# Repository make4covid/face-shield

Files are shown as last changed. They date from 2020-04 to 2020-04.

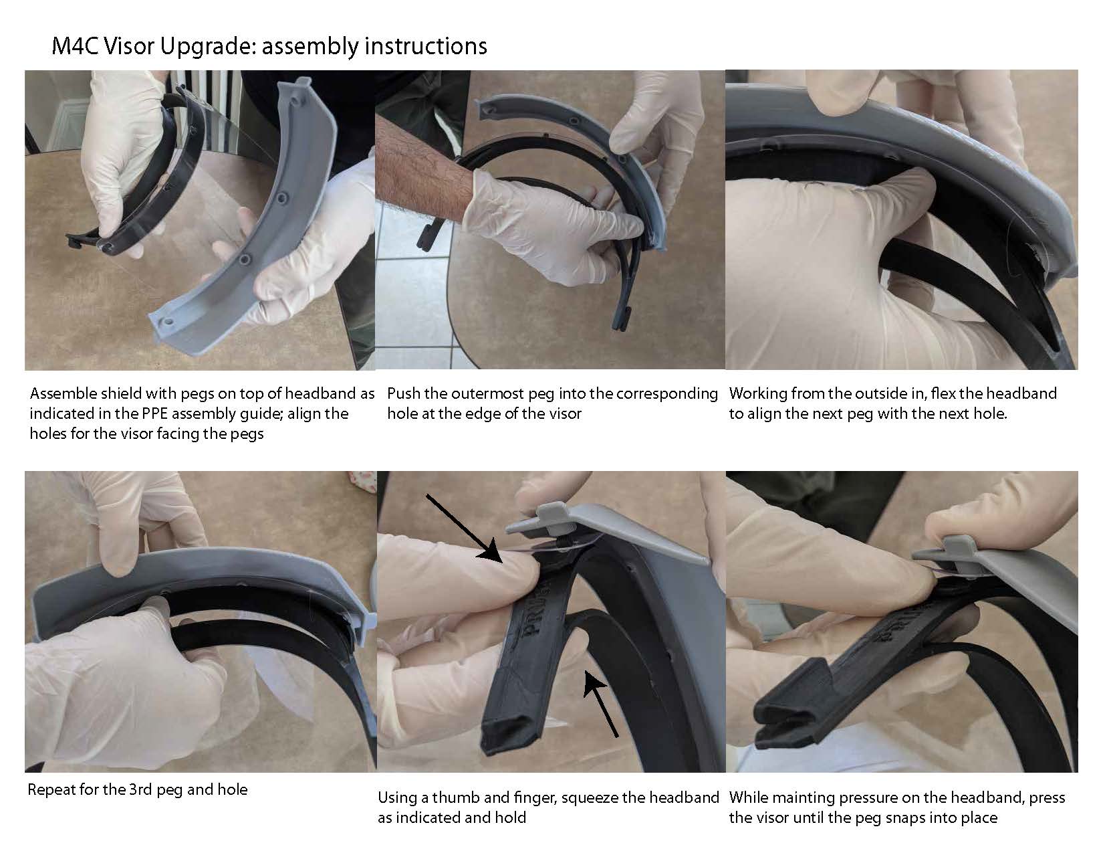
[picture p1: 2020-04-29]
M4C visor assembly instructions v1.jpg

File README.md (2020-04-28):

# Make4Covid Face Shield
### Based on the [Prusa design](https://www.prusaprinters.org/prints/25857-prusa-protective-face-shield-rc3)

This repo contains the face shield currently in production by the Make4Covid
organization. The Make4Covid design is based on [this design from Prusa](https://www.prusaprinters.org/prints/25857-prusa-protective-face-shield-rc3).

Prusa's files were released under the CC BY-SA-NC license.

**For everyone's safety, please read and follow our Standard Operating Procedures (SOPs) while making PPE for use during the COVID-19 pandemic.**

### Next Steps
1. Find, read, re-read, memorize, and bookmark [the M4C SOPs](https://github.com/make4covid/sop).
2. Download the [latest release](https://github.com/make4covid/face-shield/releases) of the design files.
3. Use the SOPs to safely make the gear!
1. If you're interested, learn [how to contribute](https://github.com/make4covid/face-shield/blob/master/CONTRIBUTING.md).

If you're in Colorado, please join our community by visiting make4covid.co and clicking 'Join.' This will allow you to connect with other Colorado makers and to leverage or growing network and supply chain to get what you make to where it's needed most!

# Derivative Design Disclaimer

These designs have been tested for comfort and safety by frontline healthcare professionals. Other people and organizations are welcome to use these designs to provide PPE to anyone who needs it.

You can fork these designs and make changes under the CC license, but in doing so, you assume liability. We encourage you to use the M4C designs unless you have the resources and facilities to adequately field-test any updated components.

# Issues?
If you find a problem with a design, compatibility between files, safety, documentation, or suggestions for improvement, please [open an issue.](https://github.com/make4covid/face-shield/issues/new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)

# Github for _hardware?_
It's not unheard of. Here are some things to keep in mind.
* Diffs don't mean much on binary files, so don't worry about them.
* Github _can_ show visual diffs on `.stl` files, so it's helpful to include them in addition to other CAD file types.
* Merging is also a challenge with binaries. Replace whole files or coordinate to avoid merge conflicts.
* Hardware repos can get huge, but you don't have to clone down everything to contribute.
* If the repo gets too big, we can set up `git lfs` (large file storage) to trim it down.

If you have other ideas on how to optimize git for open-source hardware, please [submit an issue](https://github.com/make4covid/face-shield/issues/new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) to let us know!

# Awesome Make4Covid
Check out the [Awesome M4C](https://github.com/make4covid/awesome-make4covid) repo for tons of helpful resources.

# Make4Covid
Make4Covid website is available here:

* https://www.make4covid.co/

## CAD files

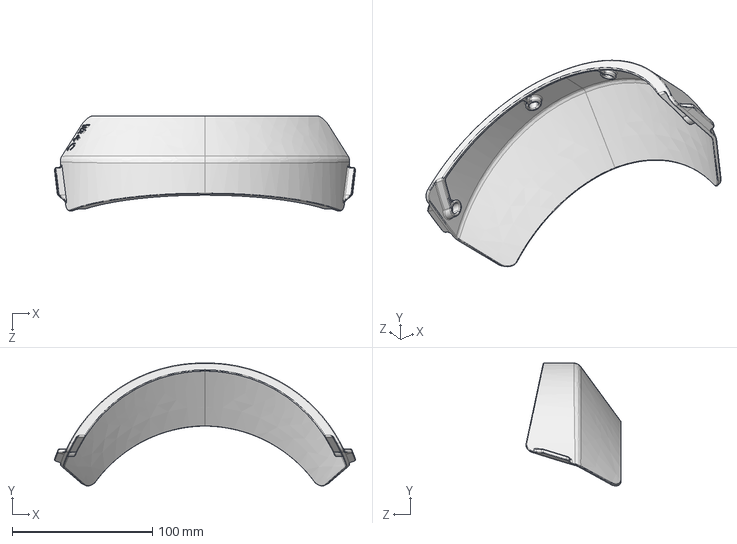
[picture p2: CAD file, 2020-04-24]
3dprint/M4C Visor Shield Rev F.1.STEP
214.6 x 87.7 x 67.8 mm

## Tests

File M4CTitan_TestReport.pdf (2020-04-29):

Face Shield Test Report M4C Titan Face Shield April 20, 2020

## 1. Summary

This report provides results from testing conducted by the Bioengineering Department on the Anschutz Medical Campus in Aurora Colorado. Test procedures were adapted from the American National Standards Institute (ANSI) standard Z87.1-2003 [1] and guidelines compiled for the Journal of Occupational and Environmental Hygiene [2]. This test does not assess mechanical impacts.

1.1. Test Articles
Test articles reported on are described in Table 1.

Table 1: Test articles.
Test Article | Part #/Lot # | Number of Samples | Material | Date
Make4Covid Titan Face Shield w/ Visor | Not Provided | 2 Shields 2 Halos 2 V1 Visors 2 V2 Visors 1 TPU Band | PETG PETG PETG PETG TPU | 4/20/2020
1.2. Results Summary
Results are summarized
in Table 2. Specifications were derived from the
ANSI standards and the
clinical guidelines [1,2]. When the shields arrived,
they were assembled
according to the
instructions for use
(Figure 1). The shields
studied were functional,

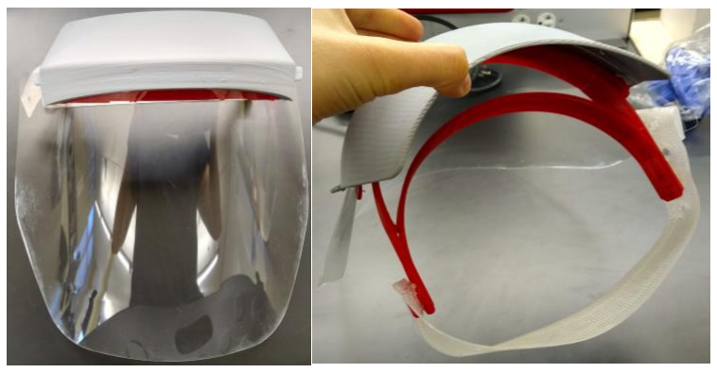
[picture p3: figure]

demonstrating no flammability, no liquid penetration during spraying, and no vision impairment or degradation after cleaning. The shields studied were not biocompatible, demonstrating irritation after 30 minutes of wear. The shields studied demonstrated no shifting during use, but both visor models popped off the shield during shield donning and doffing (Video in M4C Titan folder).

1.3. Recommendations
The tester attempted to remove the films with a razor blade (as pictured in the instructions for use) and accidentally cut off a portion of the shield edge. To improve ease of use and prevent damage, it is recommended that the film edge

Figure 1: Assembled test article.

is partially lifted for quick and damage-free film removal. To prevent the visors from popping off the halos during donning and doffing, a reduction in flexibility of the front portion of the halo is recommended. The tester experienced hair catching on the TPU band during wear tests. To improve usability, it is recommended that a non-sticky elastic securement method be used. To improve biocompatibility, it is recommended that padding be added to the forehead-contacting part of the halo.

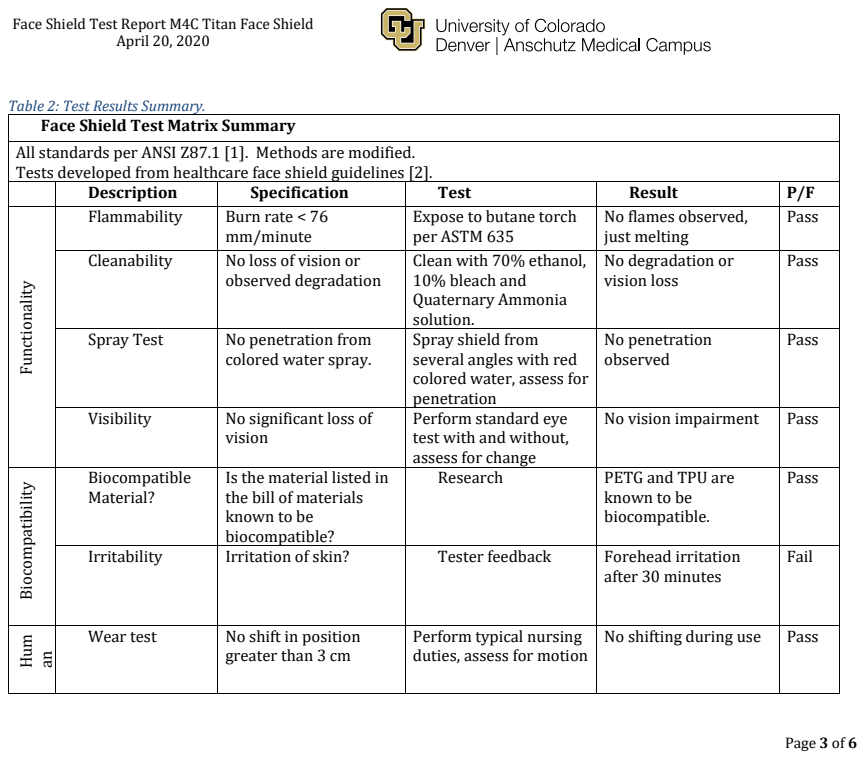
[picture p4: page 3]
April 20, 2020; Page 3 of 6; Functionality; Biocompatibility; Hum

Table 2: Test Results Summary.
Face Shield Test Matrix Summary
All standards per ANSI Z87.1 [1]. Methods are modified.
Tests developed from healthcare face shield guidelines [2].

Description | Specification | Test | Result | P/F
Flammability | Burn rate < 76 mm/minute | Expose to butane torch per ASTM 635 | No flames observed, just melting | Pass

Cleanability | No loss of vision or observed degradation | Clean with 70% ethanol, 10% bleach and Quaternary Ammonia solution. | No degradation or vision loss | Pass

Spray Test | No penetration from colored water spray. | Spray shield from several angles with red colored water, assess for penetration | No penetration observed | Pass

Visibility | No significant loss of vision | Perform standard eye test with and without, assess for change | No vision impairment | Pass

Biocompatible Material? | Is the material listed in the bill of materials known to be biocompatible? | Research | PETG and TPU are known to be biocompatible. | Pass

Irritability | Irritation of skin? | Tester feedback | Forehead irritation after 30 minutes | Fail

Wear test | No shift in position greater than 3 cm | Perform typical nursing duties, assess for motion | No shifting during use | Pass

Don/Doff time Takes no more than 30 seconds to don or doff

Measure time | 10 seconds | Pass

April 20, 2020

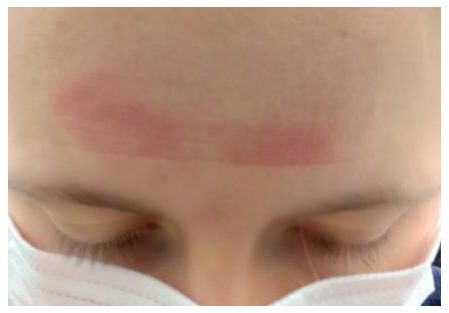
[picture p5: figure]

## 2. Results

2.1.Human Factors
When moving the head side-to-side and up-and-down repeatedly, the shield did not shift. Halo flexure caused both visor models to pop off the assembled system, which occurred during donning and doffing. In the initial wear test up to 30 minutes, forehead irritation and contact points were observed (Figure 2).

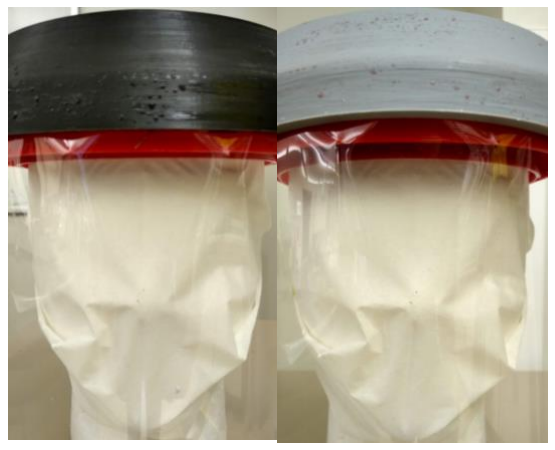
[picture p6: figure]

2.2. Spray Testing
After spraying the shield three times at eye-level from three sides, no liquid penetration was observed - no liquid was absorbed on areas protected by the face shield (Figure 3). Both visors models were tested and were functional.
2.3. Cleaning and Vision
Three test solutions, 70% ethanol, 10% bleach, and a quaternary ammonia
solution, were individually applied to
the shield before a subsequent vision
test. No damage, hazing, or reduction in vision was observed after cleaning the shield with the test solutions.
2.4. Flammability
When applying a butane flame to the shield material, no flames or burning were observed. The material melted but did not ignite. Burn rate was not recorded as no burning was observed.

## 3. Conclusion

The shield provided satisfactory visual quality and good cleanability. The visors prevented liquid penetration, but were not stable during donning and doffing. The material is not flammable and is known to be biocompatible. The tester experienced discomfort during wear.

Figure 2: User forehead after use.

Figure 3: Shield with visor model 1 (left) and visor model 2 (right) post-spray test.

## 4. References

[1] American National Standards Institute. "ANSI Z87. 1‐2003 Standard Practice for Occupational and Educational Eye and Face Protection." (2003).
[2] Roberge, Raymond J. "Face shields for infection control: A review." Journal of Occupational and Environmental Hygiene, 13.4 (2016): 235-242.

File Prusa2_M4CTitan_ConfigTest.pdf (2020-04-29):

Face Shield Test Report Prusa (v2)-Titan Face Shield Config. April 22, 2020

## 1. Summary

This report provides results from testing conducted by the Bioengineering Department on the Anschutz Medical Campus in Aurora Colorado. Test procedures were adapted from the American National Standards Institute (ANSI) standard Z87.1-2003 [1] and guidelines compiled for the Journal of Occupational and Environmental Hygiene [2]. This test does not assess mechanical impacts.

1.1. Test Articles
Test articles reported on are described in Table 1.

Table 1: Test articles.

1.2. Summary of Reconfiguration The purpose of the
following tests was
to see if
reconfiguring the
Prusa v2 shield with
visors from the Titan
system would modify
previous relevant
test results. Initially,
when using the full
Prusa v2 system with

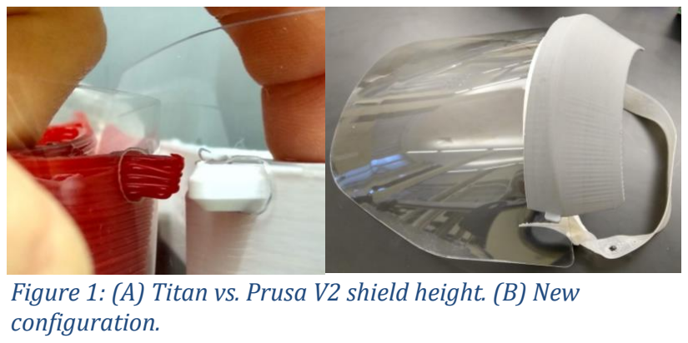
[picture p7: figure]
configuration.

the visor addition, neither visor models were able to attach to the assembly due to greater shield height (Figure 1A). Flipping the halo facilitated visor attachment successfully in the reconfigured device (Figure 1B). Both visor models were able to attach to the Prusa v2 system successfully when shield height over the halo was minimized.

Test Article | Part #/Lot # | Number of Samples | Material | Date
Prusa RC2/3 v2 | Not Provided | 2 Shields 2 Halos 2 Rubber Bands | PETG PETG | Original Tests: 4/8/2020 4/9/2020
Make4Covid Titan Face Shield w/ Visor | Not Provided | 2 Shields 2 Halos 2 V1 Visors 2 V2 Visors 1 TPU Band | PETG PETG PETG PETG TPU | Original Tests: 4/20/2020

Figure 1: (A) Titan vs. Prusa V2 shield height. (B) New

## 2. Additional Results

2.1.Usability
Halo flexure did not
cause either visor
model to pop off,
including during
donning and doffing
(Videos in
VisorConfig2 Folder).
2.2. Spray Testing
Halo flipping was
previously used to

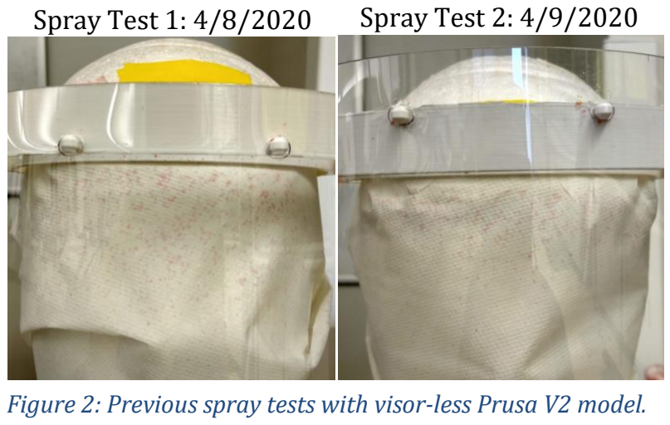
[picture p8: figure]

reduce liquid penetration in the visor-less Prusa v2
system (Figure 2). With the addition of both visor
models, no liquid
penetration was observed
(Figure 3).

## 3. Additional Conclusions

The addition of a visor has allowed the Prusa v2 system to pass spray testing. Additionally,
the Prusa v2 halo has improved
usability over the titan system

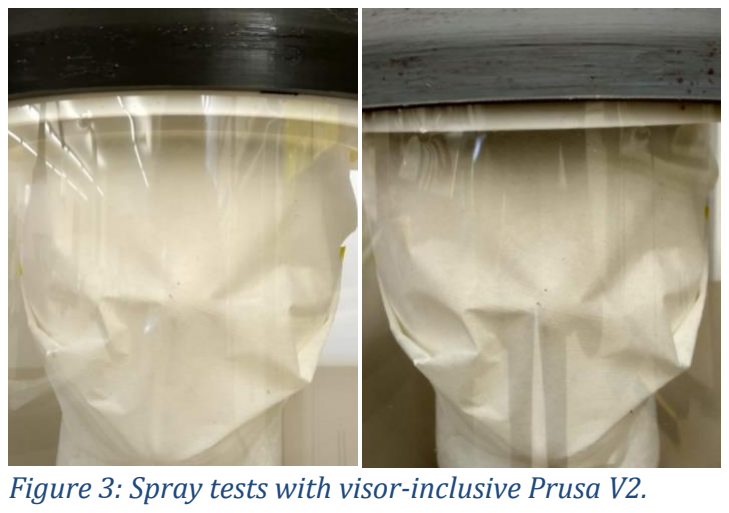
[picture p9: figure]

since flexure does not cause the visor to pop off. Given that many shield configurations are possible within these systems, visual cues on the device could ensure users can quickly assemble the system (ie. “This Side Up!”). Recommendations regarding forehead padding, the elastic strap, and shield films still remain: added padding would reduce irritability, a non-sticky elastic strap would prevent hair pulling, and peeling up the shield films slightly before shipping would improve usability.

## 4. References

[1] American National Standards Institute. "ANSI Z87. 1‐2003 Standard Practice for Occupational and Educational Eye and Face Protection." (2003).
[2] Roberge, Raymond J. "Face shields for infection control: A review." Journal of Occupational and Environmental Hygiene, 13.4 (2016): 235-24

Spray Test 1: 4/8/2020 Spray Test 2: 4/9/2020

Figure 2: Previous spray tests with visor-less Prusa V2 model.

Figure 3: Spray tests with visor-inclusive Prusa V2.

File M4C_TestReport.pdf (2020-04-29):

Face Shield Test Report Inworks Prusa Face Shield (v2) April 8, 2020

## 1. Summary

This report provides results from testing conducted by the Bioengineering Department on the Anschutz Medical Campus in Aurora Colorado. Test procedures were adapted from the American National Standards Institute (ANSI) standard Z87.1-2003 [1] and guidelines compiled for the Journal of Occupational and Environmental Hygiene [2]. This test does not assess mechanical impacts.

1.1. Test Articles
Test articles reported on are described in Table 1.

Table 1: Test articles.
Test Article | Part #/Lot # | Number of Samples | Material | Date
Prusa RC2/3 v2 | Not Provided | 2 Shields 2 Halos 2 Rubber Bands | PETG | 4/8/2020
1.2. Results Summary
Results are summarized in Table 2. Specifications were derived from the ANSI standards and the clinical guidelines [1,2]. When the test articles arrived, there appeared to be manufacturing
defects on the skin-contacting part of
the halo (Figure 1a); they otherwise
appeared as pictured on the submission form (Figure 1b). The shields studied were partially functional, demonstrating no flammability and no vision impairment or degradation after cleaning, but liquid penetration was observed during spraying. The shields tested demonstrated no shifting during use, but the rubber band made shield removal difficult due to catching of the tester’s hair. The shields studied were not biocompatible, demonstrating skin irritation after a short period of use.

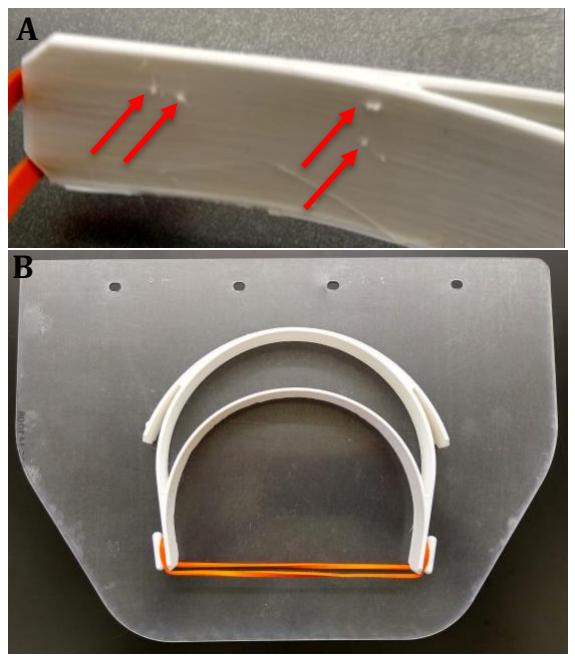
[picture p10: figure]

Figure 1: Test article upon arrival.

1.3. Recommendations
The tester spent a significant amount of the application time trying to peel the shield-covering films off. To improve ease of use and reduce user application time, it is recommended that the films be removed prior to shipment or that they be partially removed to facilitate quick removal in the clinical environment. To improve device functionality, multiple device openings should be sealed: the shield attachment points (Figure 2) and the gap between the forehead and outer halo (Figure 3). To improve biocompatibility, forehead padding would reduce redness and irritation. To prevent hair catching for user’s with longer hair, an alternative elastic backing should be considered.

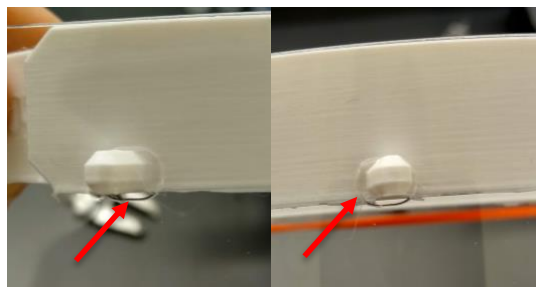
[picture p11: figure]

Figure 3: Openings at shield attachment points.

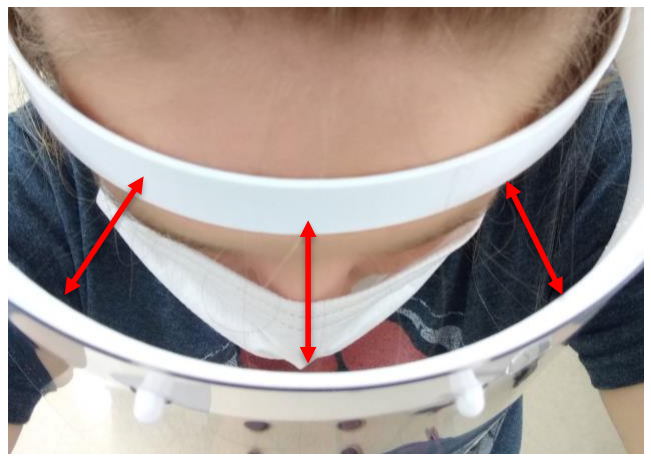
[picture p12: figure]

Figure 2: Opening between forehead and outer halo.

April 8, 2020; Page 3 of 6; Functionality; Biocompatibility

Table 2: Test Results Summary.
Face Shield Test Matrix Summary
All standards per ANSI Z87.1 [1]. Methods are modified.
Tests developed from healthcare face shield guidelines [2].

Description | Specification | Test | Result | P/F
Flammability | Burn rate < 76 mm/minute | Expose to butane torch per ASTM 635 | No flames observed, just melting | Pass

Cleanability | No loss of vision or observed degradation | Clean with 70% ethanol, 10% bleach and Quaternary Ammonia solution. | No degradation or vision loss | Pass

Spray Test | No penetration from colored water spray. | Spray shield from several angles with red colored water, assess for penetration | Penetration observed | Fail

Visibility | No significant loss of vision | Perform standard eye test with and without, assess for change | No vision impairment | Pass

Biocompatible Material? | Is the material listed in the bill of materials known to be biocompatible? | Research | PETG is known to be biocompatible | Pass

Irritability | Irritation of skin? | Tester feedback | Skin irritation and contact redness at forehead after 30 minutes, side head pain | Fail

Human Factors

Wear test | No shift in position greater than 3 cm | Perform typical nursing duties, assess for motion | No shifting during use | Pass
Don/Doff time | Takes no more than 30 seconds to don or doff | Measure time | 1.5 minutes | Fail

April 8, 2020


## 2. Results

2.1.Human Factors
When moving the head side-to-side and up-and-down repeatedly, the shield did not shift. In the initial wear test up to 30 minutes, there was skin irritation and noticeable contact points from the shield (Figure 4). The tester experienced difficulties with donning and doffing with long hair catching on the rubber band and experienced pain at the halo end points (Figure 5).


2.2. Spray Testing
After spraying the shield three times at eye-level from three sides, liquid penetration was observed on the forehead area of the test mannequin (Figure 6). It appeared that droplets made it over the gap between the forehead and halo (Figure 3).


2.3. Cleaning and Vision
Three test solutions, 70% ethanol, 10% bleach, and a quaternary ammonia solution, were individually applied to the shield before a subsequent vision test. No damage, hazing, or reduction in vision was observed after cleaning the shield with the test solutions.
2.4. Flammability
When applying a butane flame to the shield material, no flames or burning were observed. The material melted but did not ignite. Burn rate was not recorded as no burning was observed.

## 3. Conclusion

The shield provided satisfactory visual quality, good cleanability, no flammability, and was easy to take on and off once sized to the user. The tester experienced

Figure 4: Tester’s forehead after 30 minutes of wear.

Figure 5: Location of head pain relative to halo.

Figure 6: Location of spray test liquid penetration.

discomfort during wear and experienced hair catching when donning and doffing the shield. Openings in the shield allowed liquid penetration.

## 4. References

[1] American National Standards Institute. "ANSI Z87. 1‐2003 Standard Practice for Occupational and Educational Eye and Face Protection." (2003).
[2] Roberge, Raymond J. "Face shields for infection control: A review." Journal of Occupational and Environmental Hygiene, 13.4 (2016): 235-242.

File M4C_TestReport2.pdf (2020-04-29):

Face Shield Test Report Inworks Prusa Face Shield (v2) April 9, 2020

## 1. Summary

This report provides results from testing conducted by the Bioengineering Department on the Anschutz Medical Campus in Aurora Colorado. Test procedures were adapted from the American National Standards Institute (ANSI) standard Z87.1-2003 [1] and guidelines compiled for the Journal of Occupational and Environmental Hygiene [2]. This test does not assess mechanical impacts.

1.1. Test Articles
Test articles reported on are described in Table 1.

Table 1: Test articles.
Test Article | Part #/Lot # | Number of Samples | Material | Date
Prusa RC2/3 v2 | Not Provided | 2 Shields 2 Halos 2 Rubber Bands | PETG | 4/8/2020

## 2. Additional Results

2.1. Spray Testing
After initial spray testing on 4/8/2020, an alternative shield configuration was recommended for additional spray testing. As previously, the shield was sprayed three times at eye-level from three sides. Liquid penetration was observed on the forehead area of the test mannequin in both shield configurations (Figures 1 & 2). It appeared that droplets made it over the gap between the forehead and halo (Figure 1). The degree of liquid penetration observed was reduced in the secondary spray test with the inverted shield configuration.


Spray Test 1: 4/8/2020 | Spray Test 2: 4/9/2020

Figure 1: Top view spray testing comparison.


## Additional Conclusions

Openings in the shield allowed liquid penetration. When the halo was in a flipped configuration for Spray Test 2, the elevated shield reduced liquid penetration from droplets traversing the forehead-halo gap. Given that liquid penetration was still observed, the previous recommendations for functionality are the same: openings at the shield attachment points and at the forehead-halo gap should be sealed to prevent liquid penetration. Additionally, if one halo configuration is preferred, it should be included in instructions for use and/or demonstrated through visual user cues on the device (ie. “This Side Up!”).

## 3. References

[1] American National Standards Institute. "ANSI Z87. 1‐2003 Standard Practice for Occupational and Educational Eye and Face Protection." (2003).
[2] Roberge, Raymond J. "Face shields for infection control: A review." Journal of Occupational and Environmental Hygiene, 13.4 (2016): 235-24
Spray Test 1: 4/8/2020 | Spray Test 2: 4/9/2020

Figure 2: Front view spray testing comparison.

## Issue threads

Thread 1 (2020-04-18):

RC3 4 Stack

wfischer42, 2020-04-18:
What kind of issue are you reporting?
- [x] Other
- [ ] Design files that should be compatible are not
- [ ] Safety concern for specific design
- [ ] Printer compatibility issue
- [ ] Print settings issue

Additional comments:
If it's ready, I'd like this to include an approved Prusa 4-stack design file!

Closed 2020-04-29.
